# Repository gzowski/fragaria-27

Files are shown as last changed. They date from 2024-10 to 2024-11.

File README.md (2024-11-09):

# Fragaria-27
27 Key macropad with MX hotswap sockets, designed to fit within a iphone 13/14 pro max case giving many options given the amount of phone case options available.

* This is another project which has been possible thanks to the sponsorship from pcbway.com 

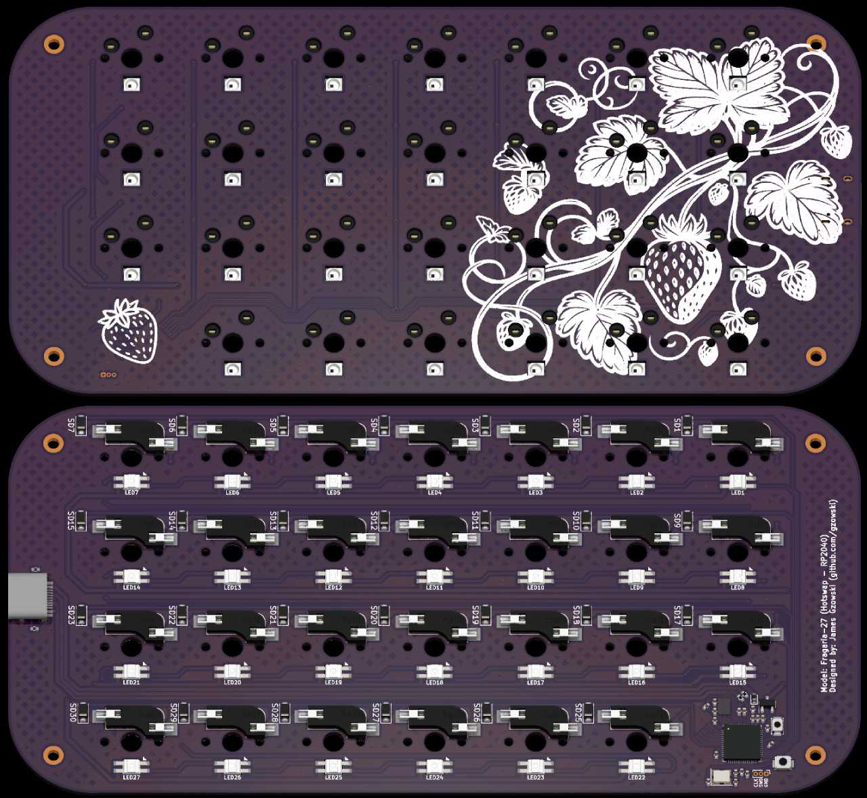
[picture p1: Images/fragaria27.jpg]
Fragaria-27-rev1


## Features
* 27 Key layout
* Per key RGB LED's
* Embedded RP2040 controller
* QMK Firmware with VIA support
* Fits into an iphone 13/14 Pro Max case
* 4 mounting screws for custom case designs

* Currently working on a one handed keyboard mode using chord

## Parts
| Part | Quantity | Description |
| :--- | :--- | :--- |
| Switches | 27 | MX Switches |
| Keycaps | 27 | 1U Keycaps |
| PCB Components | - | Included in kicad design and within PCB/bom/ibom.html |
## Optional Parts

| Part | Quantity | Description |
| :--- | :--- | :--- |
| Phone Case | 1 | iPhone 13/14 Pro Max case |

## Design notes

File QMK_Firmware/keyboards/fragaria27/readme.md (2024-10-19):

# Fragaria-27

27 Key Macropad

* Keyboard Maintainer: [James Gzowski](https://github.com/gzowski)
* Hardware Supported: Embedded RP2040
* Build Guide: [Somei70](https://github.com/gzowski/fragaria-27)

Make example for this keyboard (after setting up your build environment):
	
    make fragaria27:default

Flashing example for this keyboard:

    make fragaria27:default:flash

See the [build environment setup](https://docs.qmk.fm/#/getting_started_build_tools) and the [make instructions](https://docs.qmk.fm/#/getting_started_make_guide) for more information. Brand new to QMK? Start with our [Complete Newbs Guide](https://docs.qmk.fm/#/newbs).

## Bootloader

* **Bootmagic reset**: Hold down the key at (0,0) in the matrix (usually the top left key or Escape) and plug in the keyboard
* **Physical reset button**: Briefly press the button on the PCB, if using a RP2040 press repeatidly to enter boot mode.
* **Hold down boot loader button on MCU** Hold down the boot loader button on the MCU while plugging in the keyboard

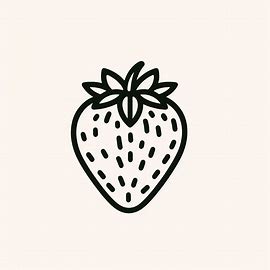
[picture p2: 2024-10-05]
PCB/silkscreen_images/strawberry.jpeg

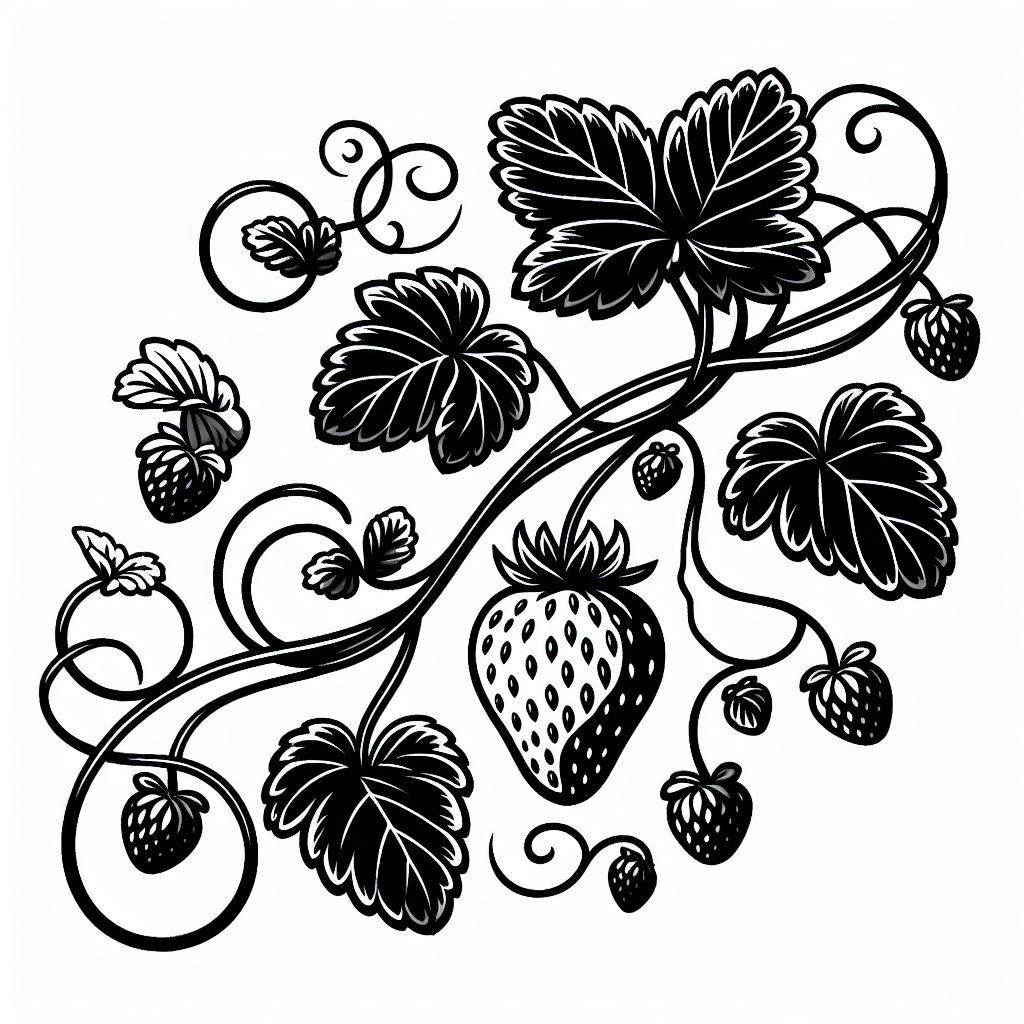
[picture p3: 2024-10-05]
PCB/silkscreen_images/frag.jpeg

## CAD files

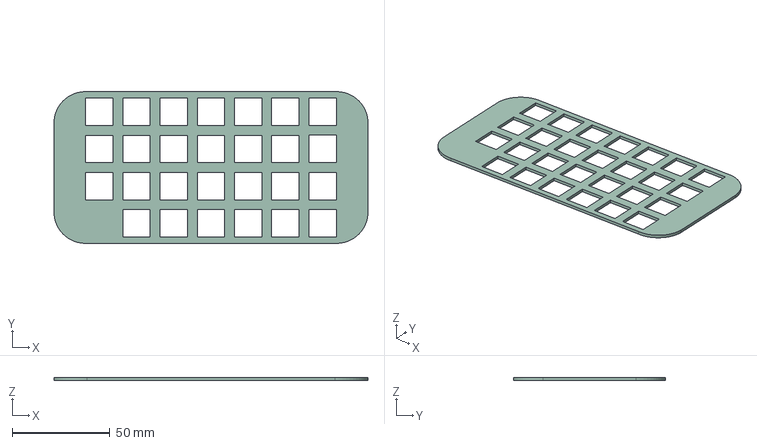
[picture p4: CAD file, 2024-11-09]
Plates/top_plate_no_screw_holes.step
160.7 x 77.6 x 1.60 mm

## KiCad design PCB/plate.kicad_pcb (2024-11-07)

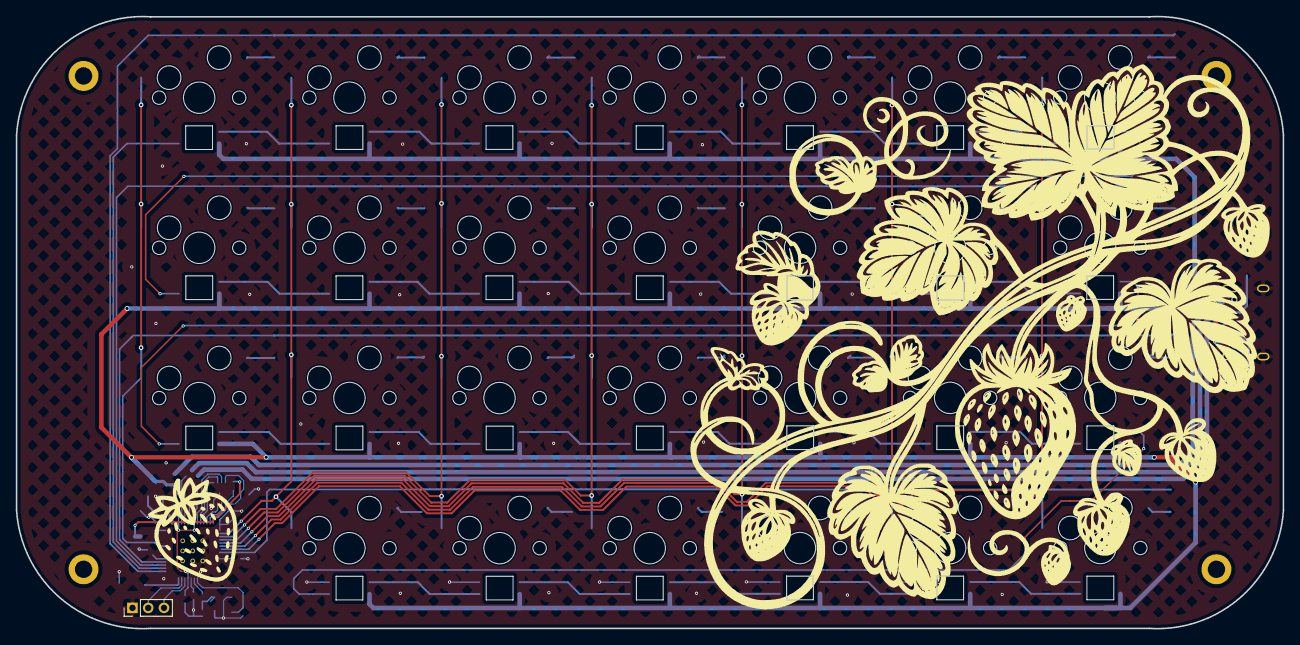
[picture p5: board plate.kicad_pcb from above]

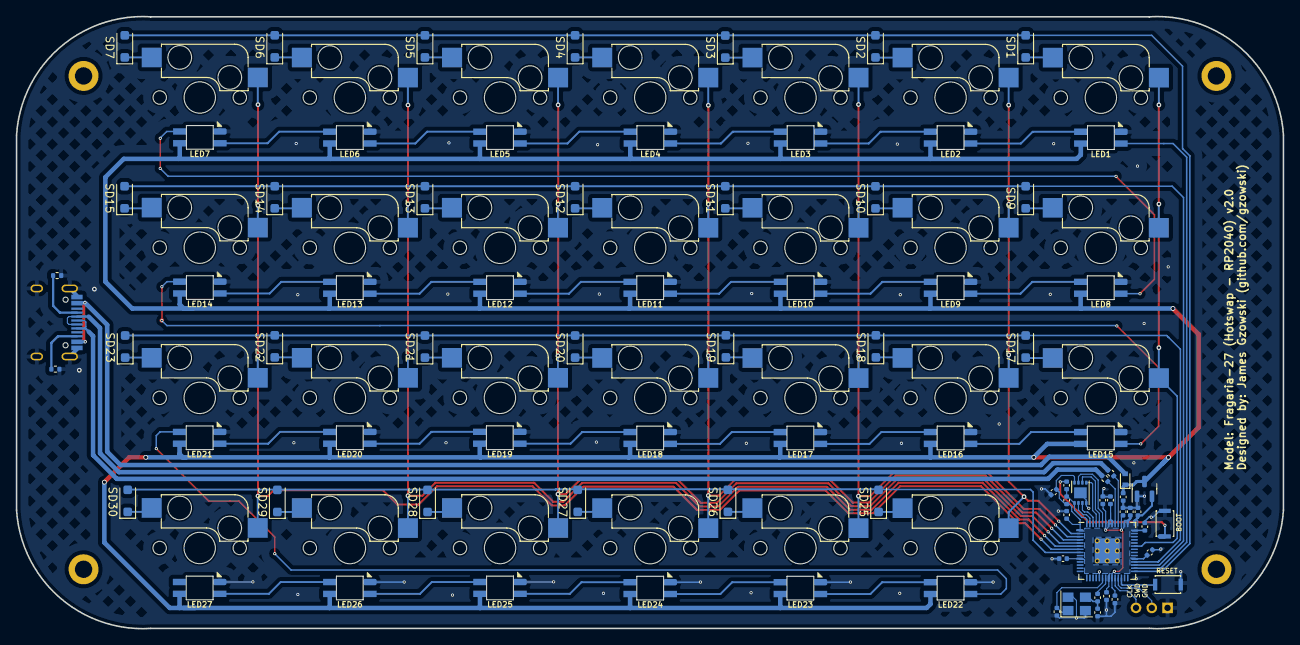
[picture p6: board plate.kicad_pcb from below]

Board: 2 copper layers, 160.7 x 77.6 mm, 116 parts (84 on the bottom side), 88 nets.

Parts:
C1, C3, C4, C10: JMK105BJ105KV-F; C_0402_1005Metric
C2, C19: GJM1555C1H220JB01D; C_0402_1005Metric
C5, C6, C7, C8, C11, C13, C14, C15, C18: CC0402KRX5R5BB104; C_0402_1005Metric
D1: RB520SM-40T2R; D_SOD-523
FLASH1: w25q16jvuxiq; SON-8-1EP_3x2mm_P0.5mm_EP1.4x1.6mm
J1, J2: KXT331LHS; SW_SPST_CK_KXT3
LED1, LED2, LED3, LED4, LED5, LED6, LED7, LED8, LED9, LED10, LED11, LED12, LED13, LED14, LED15, LED16, LED17, LED18, LED19, LED20, LED21, LED22, LED23, LED24, LED25, LED26, LED27: SK6803MINI-E-001; SK6812-MINI-E
R1, R7: CRT0402AFY-1001GLF; C_0402_1005Metric
R2: CRT0402ADY-1002GLF; C_0402_1005Metric
R3, R4: CRG0402F27R; R_0402_1005Metric
R5, R6: CR0402F5K10Q10Z; R_0402_1005Metric
SD1, SD2, SD3, SD4, SD5, SD6, SD7, SD9, SD10, SD11, SD12, SD13, SD14, SD15, SD17, SD18, SD19, SD20, SD21, SD22, SD23, SD25, SD26, SD27, SD28, SD29, SD30: 1N4148W; D_SOD-123F
SW1, SW2, SW3, SW4, SW5, SW6, SW7, SW8, SW9, SW10, SW11, SW12, SW13, SW14, SW15, SW16, SW17, SW18, SW19, SW20, SW21, SW22, SW23, SW24, SW25, SW26, SW27: CPG151101S11; SW_Cherry_MX_1.00u_PCB_HOTSWAP_Details
U1: AP2210N-3.3TRG1; SOT-23
U3: RP2040; RP2040-QFN-56
USB2: TYPE-C-31-M-12; HRO-TYPE-C-31-M-12
Y1: TAXM12M4RKDCDT2T; Crystal_SMD_3225-4Pin_3.2x2.5mm
hole: hole
hole#2, hole#3, hole#4: hole
pin: DNP; PinHeader_1x03_P2.00mm_Vertical

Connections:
+1V1: C3.1, C6.1, C7.1, U3.23 (DVDD), U3.45 (VREG_VOUT), U3.50 (DVDD)
+3V3: C4.1, C5.1, C8.1, C10.1, C11.1, C13.1, C14.1, C15.1, C18.1, FLASH1.8 (VCC), R2.1, U1.2 (VO), U3.1 (IOVDD), U3.10 (IOVDD), U3.22 (IOVDD), U3.33 (IOVDD), U3.42 (IOVDD), U3.43 (ADC_AVDD), U3.44 (VREG_IN), U3.48 (USB_VDD), U3.49 (IOVDD)
/QSPI_SCLK: FLASH1.6 (CLK), U3.52 (QSPI_SCLK)
/QSPI_SD0: FLASH1.5 (DI(IO0)), U3.53 (QSPI_SD0)
/QSPI_SD1: FLASH1.2 (DO(IO1)), U3.55 (QSPI_SD1)
/QSPI_SD2: FLASH1.3 (IO2), U3.54 (QSPI_SD2)
/QSPI_SD3: FLASH1.7 (IO3), U3.51 (QSPI_SD3)
/QSPI_SS: FLASH1.1 (~CS), R1.1, R2.2, U3.56 (QSPI_SS)
/RUN: J1.1, U3.26 (RUN)
/SWCLK: U3.24 (SWCLK), pin.3
/SWD: U3.25 (SWD), pin.2
/USB_D+: R3.1, USB2.6 (DP1), USB2.8 (DP2)
/USB_D-: R4.1, USB2.5 (DN2), USB2.7 (DN1)
/~USB_BOOT: J2.1, R1.2
COL1: SW1.2, SW8.2, SW15.2, U3.37 (GPIO25)
COL2: SW2.2, SW9.2, SW16.2, SW22.2, U3.2 (GPIO0)
COL3: SW3.2, SW10.2, SW17.2, SW23.2, U3.3 (GPIO1)
COL4: SW4.2, SW11.2, SW18.2, SW24.2, U3.4 (GPIO2)
COL5: SW5.2, SW12.2, SW19.2, SW25.2, U3.5 (GPIO3)
COL6: SW6.2, SW13.2, SW20.2, SW26.2, U3.6 (GPIO4)
COL7: SW7.2, SW14.2, SW21.2, SW27.2, U3.7 (GPIO5)
GND: C1.2, C2.2, C3.2, C4.2, C5.2, C6.2, C7.2, C8.2, C10.2, C11.2, C13.2, C14.2, C15.2, C18.2, C19.2, FLASH1.4 (GND), FLASH1.9 (EP), J1.2, J2.2, LED1.3 (VSS), LED2.3 (VSS), LED3.3 (VSS), LED4.3 (VSS), LED5.3 (VSS), LED6.3 (VSS), LED7.3 (VSS), LED8.3 (VSS), LED9.3 (VSS), LED10.3 (VSS), LED11.3 (VSS), LED12.3 (VSS), LED13.3 (VSS), LED14.3 (VSS), LED15.3 (VSS), LED16.3 (VSS), LED17.3 (VSS), LED18.3 (VSS), LED19.3 (VSS), LED20.3 (VSS), LED21.3 (VSS), LED22.3 (VSS), LED23.3 (VSS), LED24.3 (VSS), LED25.3 (VSS), LED26.3 (VSS), LED27.3 (VSS), R5.1, R6.1, U1.1 (GND), U3.19 (TESTEN), U3.57 (GND), USB2.1 (GND), USB2.12 (GND), USB2.13 (SHIELD), Y1.2, Y1.4, pin.1
LED_D_IN: LED1.4 (DIN), U3.30 (GPIO19)
unnamed: LED1.2 (DOUT), LED2.4 (DIN)
unnamed: LED2.2 (DOUT), LED3.4 (DIN)
unnamed: LED3.2 (DOUT), LED4.4 (DIN)
unnamed: LED4.2 (DOUT), LED5.4 (DIN)
unnamed: LED5.2 (DOUT), LED6.4 (DIN)
unnamed: LED6.2 (DOUT), LED7.4 (DIN)
unnamed: LED7.2 (DOUT), LED8.4 (DIN)
unnamed: LED8.2 (DOUT), LED9.4 (DIN)
unnamed: LED9.2 (DOUT), LED10.4 (DIN)
unnamed: LED10.2 (DOUT), LED11.4 (DIN)
unnamed: LED11.2 (DOUT), LED12.4 (DIN)
unnamed: LED12.2 (DOUT), LED13.4 (DIN)
unnamed: LED13.2 (DOUT), LED14.4 (DIN)
unnamed: LED14.2 (DOUT), LED15.4 (DIN)
unnamed: LED15.2 (DOUT), LED16.4 (DIN)
unnamed: LED16.2 (DOUT), LED17.4 (DIN)
unnamed: LED17.2 (DOUT), LED18.4 (DIN)
unnamed: LED18.2 (DOUT), LED19.4 (DIN)
unnamed: LED19.2 (DOUT), LED20.4 (DIN)
unnamed: LED20.2 (DOUT), LED21.4 (DIN)
unnamed: LED21.2 (DOUT), LED22.4 (DIN)
unnamed: LED22.2 (DOUT), LED23.4 (DIN)
unnamed: LED23.2 (DOUT), LED24.4 (DIN)
unnamed: LED24.2 (DOUT), LED25.4 (DIN)
unnamed: LED25.2 (DOUT), LED26.4 (DIN)
unnamed: LED26.2 (DOUT), LED27.4 (DIN)
unnamed: SD1.1 (K), SW1.1
unnamed: SD2.1 (K), SW2.1
unnamed: SD3.1 (K), SW3.1
unnamed: SD4.1 (K), SW4.1
unnamed: SD5.1 (K), SW5.1
unnamed: SD6.1 (K), SW6.1
unnamed: SD7.1 (K), SW7.1
unnamed: SD9.1 (K), SW8.1
unnamed: SD10.1 (K), SW9.1
unnamed: SD11.1 (K), SW10.1
unnamed: SD12.1 (K), SW11.1
unnamed: SD13.1 (K), SW12.1
unnamed: SD14.1 (K), SW13.1
unnamed: SD15.1 (K), SW14.1
unnamed: SD17.1 (K), SW15.1
unnamed: SD18.1 (K), SW16.1
unnamed: SD19.1 (K), SW17.1
unnamed: SD20.1 (K), SW18.1
unnamed: SD21.1 (K), SW19.1
unnamed: SD22.1 (K), SW20.1
unnamed: SD23.1 (K), SW21.1
unnamed: SD25.1 (K), SW22.1
unnamed: SD26.1 (K), SW23.1
unnamed: SD27.1 (K), SW24.1
unnamed: SD28.1 (K), SW25.1
unnamed: SD29.1 (K), SW26.1
unnamed: SD30.1 (K), SW27.1
unnamed: R4.2, U3.46 (USB_DM)
unnamed: R3.2, U3.47 (USB_DP)
unnamed: C19.1, U3.20 (XIN), Y1.1
unnamed: C2.1, R7.1, R7.2, U3.21 (XOUT), Y1.3
unnamed: R5.2, USB2.4 (CC1)
unnamed: R6.2, USB2.10 (CC2)
ROW1: SD1.2 (A), SD2.2 (A), SD3.2 (A), SD4.2 (A), SD5.2 (A), SD6.2 (A), SD7.2 (A), U3.29 (GPIO18)
ROW2: SD9.2 (A), SD10.2 (A), SD11.2 (A), SD12.2 (A), SD13.2 (A), SD14.2 (A), SD15.2 (A), U3.31 (GPIO20)
ROW3: SD17.2 (A), SD18.2 (A), SD19.2 (A), SD20.2 (A), SD21.2 (A), SD22.2 (A), SD23.2 (A), U3.32 (GPIO21)
ROW4: SD25.2 (A), SD26.2 (A), SD27.2 (A), SD28.2 (A), SD29.2 (A), SD30.2 (A), U3.8 (GPIO6)
VBUS: D1.2 (A), USB2.2 (VBUS), USB2.11 (VBUS)
vsys: C1.1, D1.1 (K), LED1.1 (VDD), LED2.1 (VDD), LED3.1 (VDD), LED4.1 (VDD), LED5.1 (VDD), LED6.1 (VDD), LED7.1 (VDD), LED8.1 (VDD), LED9.1 (VDD), LED10.1 (VDD), LED11.1 (VDD), LED12.1 (VDD), LED13.1 (VDD), LED14.1 (VDD), LED15.1 (VDD), LED16.1 (VDD), LED17.1 (VDD), LED18.1 (VDD), LED19.1 (VDD), LED20.1 (VDD), LED21.1 (VDD), LED22.1 (VDD), LED23.1 (VDD), LED24.1 (VDD), LED25.1 (VDD), LED26.1 (VDD), LED27.1 (VDD), U1.3 (VI)

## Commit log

2024-10-05 First push
    [MacroPadPro.kicad_pcb, MacroPadPro.kicad_sch]
2024-10-06 Updated PCB and added BOM
    [MacroPadPro.kicad_pcb]
2024-10-18 Images and Readme.MD
    [MacroPadPro.kicad_pcb]
2024-11-07 Updated PCB design to fix GND fault and update BOM components
    [MacroPadPro.kicad_pcb, MacroPadPro.kicad_sch]
2024-11-07 Updated BOM components, fixed with known working parts
    [MacroPadPro.kicad_pcb]
2024-11-09 Updating firmware, one handed full keyboard options
    [plate.kicad_pcb, top_plate_no_screw_holes.step, topplate.kicad_pcb]
